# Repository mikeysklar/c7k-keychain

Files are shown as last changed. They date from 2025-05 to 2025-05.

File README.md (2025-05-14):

# c7k-keychain
super thin I2C keyboard

Chording 7 Key - I2C breakout

Ultra-Thin wearable one handed keyboard which can be used with a phone, tablet, computer even from a pocket. It is a full size keybaord in seven buttons.

I2C interface means easy connectivity to modern micrcontrollers and single board computers. This allows maximum flexibility for direct to controller, HID USB or HID BLE interfacing.

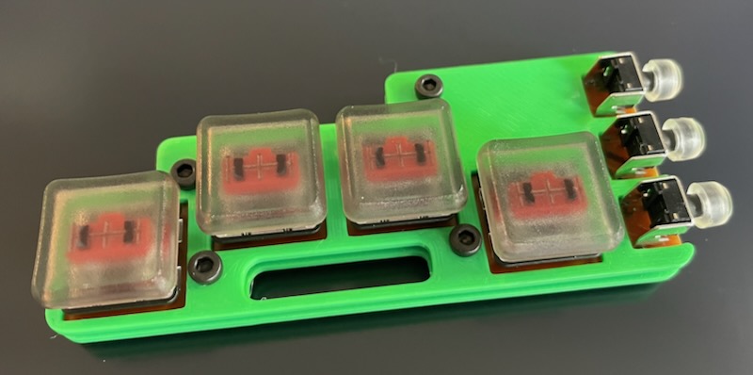
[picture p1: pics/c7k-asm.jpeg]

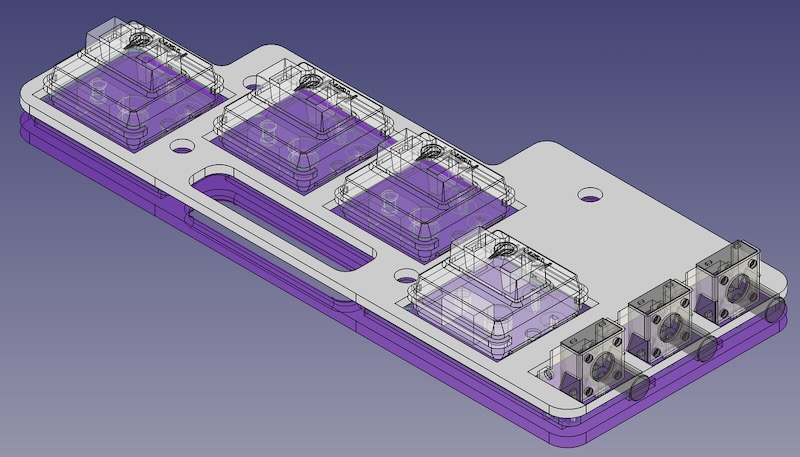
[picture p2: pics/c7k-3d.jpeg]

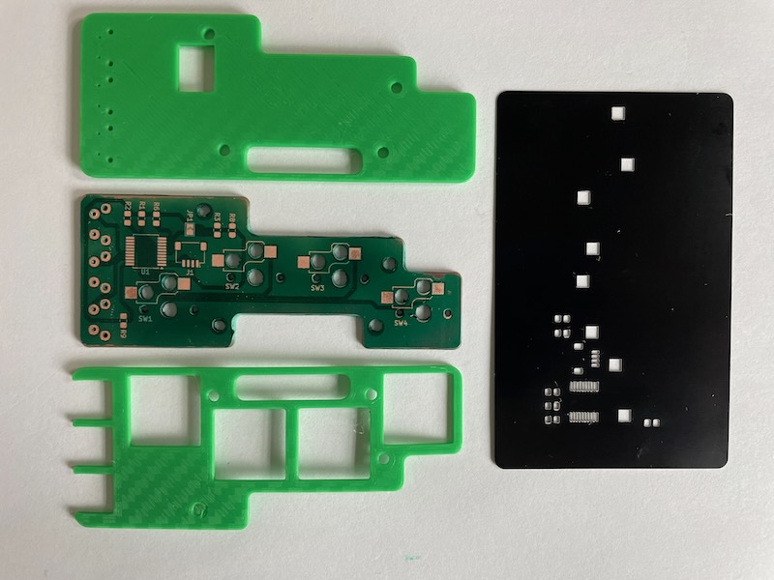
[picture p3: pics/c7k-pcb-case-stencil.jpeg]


center thumb or no modifier :: alpha
```
| Key | Pinky | Ring | Middle | Index | Thumb |
|-----|-------|------|--------|-------|-------|
| a   | x     |      |        |       |       |
| b   | x     |      |        |       | oxo   |
| c   | x     |      |        | x     |       |
| d   |       | x    | x      | x     |       |
| e   |       |      | x      |       |       |
| f   |       | x    | x      |       | oxo   |
| g   |       |      | x      |       | oxo   |
| h   |       | x    |        |       | oxo   |
| i   |       |      | x      |       |       |
| j   |       | x    | x      | x     | oxo   |
| k   | x     |      | x      |       | oxo   |
| l   | x     |      | x      |       |       |
| m   |       |      |        | x     | oxo   |
| n   |       | x    | x      |       |       |
| o   |       | x    |        | x     |       |
| p   | x     | x    | x      |       |       |
| q   | x     | x    | x      | x     | oxo   |
| r   |       |      | x      | x     |       |
| s   | x     |      |        |       |       |
| t   | x     | x    |        |       |       |
| u   | x     | x    | x      | x     |       |
| v   | x     | x    |        |       | oxo   |
| w   |       | x    |        | x     | oxo   |
| x   | x     |      |        | x     | oxo   |
| y   |       |      | x      | x     | oxo   |
| z   | x     | x    | x      |       | oxo   |
| BCK | x     |      | x      | x     |       |
| SPC | x     | x    |        | x     |       |
| DEL | x     |      | x      | x     | oxo   |
```

outside thumb modifier :: numeric

```
| Key   | Pinky | Ring | Middle | Index | Thumb |
|-------|-------|------|--------|-------|-------|
| ONE   |       |      |        | x     | oox   |
| TWO   |       |      | x      |       | oox   |
| THREE |       | x    |        |       | oox   |
| FOUR  | x     |      |        |       | oox   |
| FIVE  |       |      | x      | x     | oox   |
| SIX   |       | x    | x      |       | oox   |
| SEVEN | x     | x    |        |       | oox   |
| EIGHT |       | x    |        | x     | oox   |
| NINE  | x     |      | x      |       | oox   |
| ZERO  |       | x    | x      | x     | oox   |
| ->    | x     |      | x      | x     | oox   |
| <-    | x     | x    |        | x     | oox   |
| ^^    | x     |      |        | x     | oox   |
| vv    | x     | x    | x      | x     | oox   |
| ESC   | x     | x    | x      |       | oox   |
```

inside thumb :: white 

```
| Key            | Pinky | Ring | Middle | Index | Thumb |
|----------------|-------|------|--------|-------|-------|
| space          |       |      |        | x     | xoo   |
| tab            |       |      | x      |       | xoo   |
| period         |       | x    |        |       | xoo   |
| minus          | x     |      |        |       | xoo   |
| comma          |       | x    |        | x     | xoo   |
| enter          |       |      | x      | x     | xoo   |
| backspace      |       | x    | x      |       | xoo   |
| backslash      | x     | x    |        | x     | xoo   |
| forward_slash  | x     | x    |        |       | xoo   |
| grave_accent   | x     | x    | x      | x     | xoo   |
| minus          | x     |      |        |       | xoo   |
| equals         |       | x    |        | x     | xoo   |
| left_bracket   | x     |      | x      |       | xoo   |
| right_bracket  | x     |      |        | x     | xoo   |
| semicolon      | x     | x    |        | x     | xoo   |
| quote          | x     |      | x      | x     | xoo   |
```

inside and center thumb :: modifier layer

```
| Action          | Pinky | Ring | Middle | Index | Thumb |
|-----------------|:-----:|:----:|:------:|:-----:|:-----:|
| Toggle Mouse    |       |      |        |       | oxx   |
| Move Up         |   X   |      |        |       |       |
| Move Right      |       |   X  |        |       |       |
| Move Left       |       |      |   X    |       |       |
| Move Down       |       |      |        |   X   |       |
| Left Click      |   X   |   X  |        |       |       |
| Right Click     |       |      |   X    |   X   |       |
| Middle Click    |       |   X  |   X    |       |       |
| Back (X1)       |   X   |      |        |       |   X   |
| Forward (X2)    |       |      |        |   X   |   X   |
```

inside and outer thumb :: mouse layer

```
| Action       | Pinky | Ring | Middle | Index | Thumb |
|--------------|-------|------|--------|-------|-------|
| Toggle Mouse |       |      |        |       | oxx   |
| Move Up      | x     |      |        |       |       |
| Move Right   |       | x    |        |       |       |
| Move Left    |       |      | x      |       |       |
| Move Down    |       |      |        | x     |       |
```

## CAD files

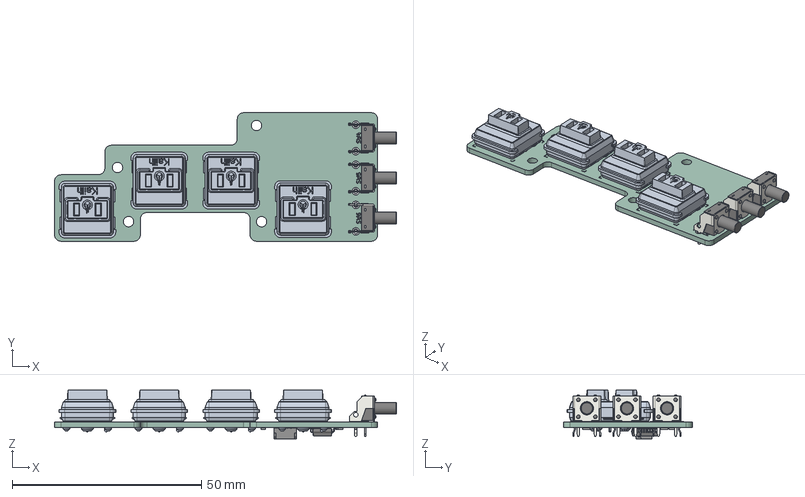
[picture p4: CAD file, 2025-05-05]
c7k-left-hand/c7k-left-hand.step
90.4 x 34.0 x 12.9 mm
SW_Tactile_SPST_Angled_PTS645Vx83-2LFS x 3
Kailh LP Choc Burnt Orange x 4
R_0805_2012Metric x 6
SSOP-20_5.3x7.2mm_P0.65mm
SPARKFUN_QWIIC_RIGHT_ANGLE
c7k-left-hand_pad
c7k-left-hand_silkscreen
c7k-left-hand_PCB

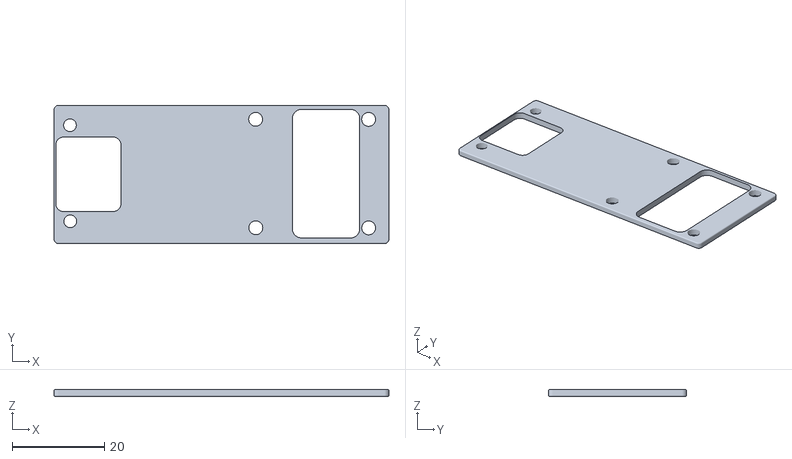
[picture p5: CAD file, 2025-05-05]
case/c7k-keychain-nnv2-cover.stl
72.6 x 30.0 x 1.50

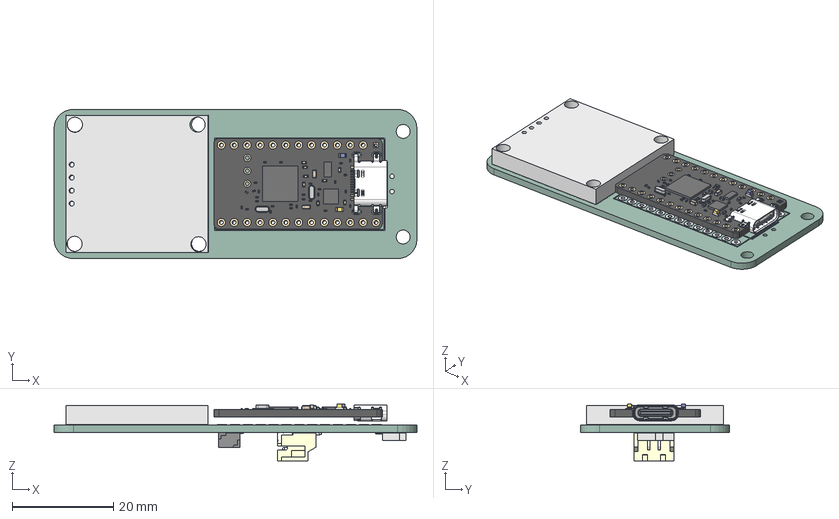
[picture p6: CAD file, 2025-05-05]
nnv2-oled-toupee/nicenano-breakout.step
71.5 x 29.4 x 11.2 mm
nice!nano v1.0
mcu-chip-ic-2set-leg v1
LED_0603_1608Metric_ON v1
LED_0603_1608Metric_ON v1(Mirror)
Crystal Oscillator v3
Crystal Oscillator v3 (1)
usb4520-03-0-a v1
C0201 v1 x 28
C0402 v1 x 8
0603 v1 x 2
SPARKFUN_QWIIC_RIGHT_ANGLE
S2B-PH-SM4-TB
nnv2-oled-toupee_pad
nnv2-oled-toupee_silkscreen
nnv2-oled-toupee_PCB

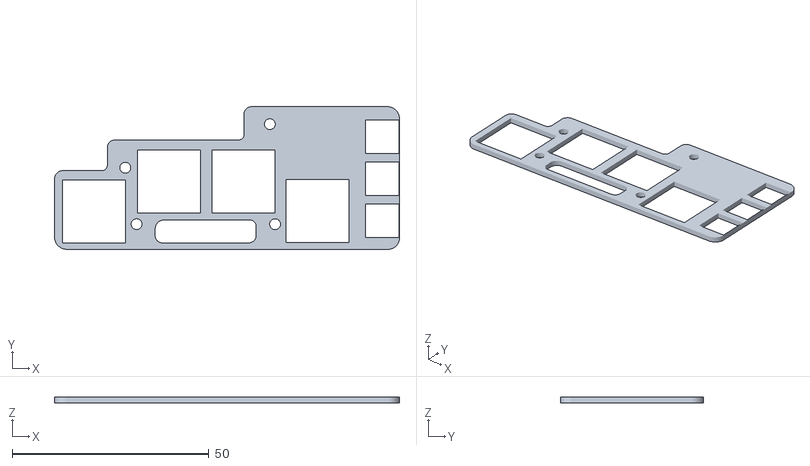
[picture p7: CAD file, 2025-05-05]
case/c7k-keychain-c7k-cover.stl
87.6 x 36.2 x 1.50

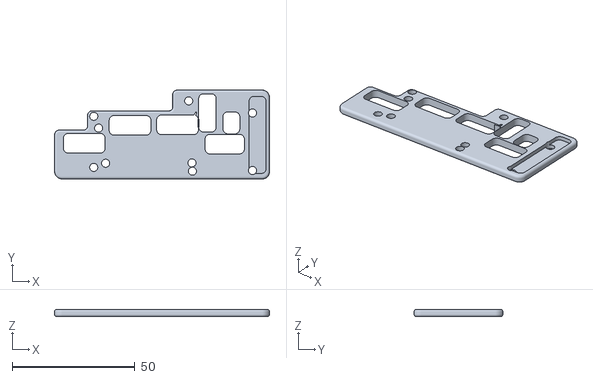
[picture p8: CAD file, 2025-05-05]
case/c7k-keychain-center-plate.stl
87.6 x 36.2 x 3.00

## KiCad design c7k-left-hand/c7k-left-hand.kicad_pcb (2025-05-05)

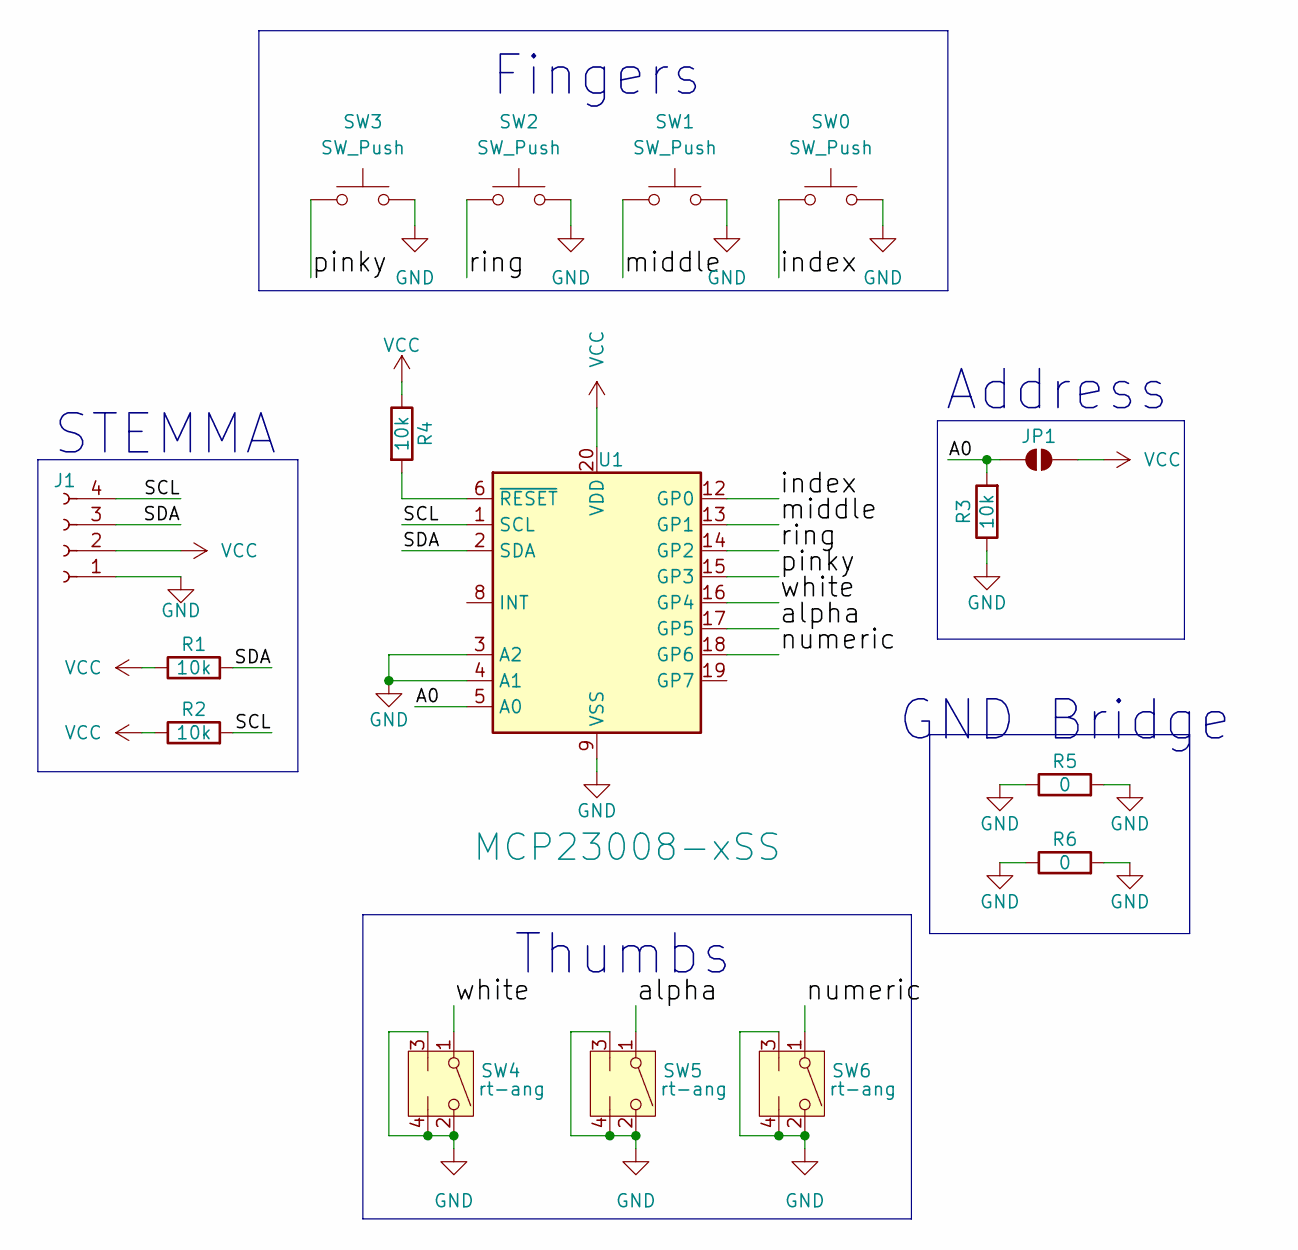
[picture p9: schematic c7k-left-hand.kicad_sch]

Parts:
J1: Conn_01x04_Socket; JST_SH_SM04B-SRSS-TB_1x04-1MP_P1.00mm_Horizontal
JP1: SolderJumper_2_Open; SolderJumper-2_P1.3mm_Open_TrianglePad1.0x1.5mm
R1, R2, R3, R4: 10k; R_0805_2012Metric_Pad1.20x1.40mm_HandSolder
R5, R6: 0; R_0805_2012Metric_Pad1.20x1.40mm_HandSolder
SW0, SW1, SW2, SW3: SW_Push; Kailh_socket_PG1350
SW4, SW5, SW6: rt-ang; SW_Tactile_SPST_Angled_PTS645Vx83-2LFS
U1: MCP23008-xSS; SSOP-20_5.3x7.2mm_P0.65mm

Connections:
/A0: JP1.1 (A), R3.2, U1.5 (A0)
/SCL: J1.4, R2.2, U1.1 (SCL)
/SDA: J1.3, R1.2, U1.2 (SDA)
/alpha: SW5.1, U1.17 (GP5)
/index: SW0.1, U1.12 (GP0)
/middle: SW1.1, U1.13 (GP1)
/numeric: SW6.1, U1.18 (GP6)
/pinky: SW3.1, U1.15 (GP3)
/ring: SW2.1, U1.14 (GP2)
/white: SW4.1, U1.16 (GP4)
GND: J1.1, R3.1, R5.1, R5.2, R6.1, R6.2, SW0.2, SW1.2, SW2.2, SW3.2, SW4.2, SW4.3 (L), SW4.4 (L), SW5.2, SW5.3 (L), SW5.4 (L), SW6.2, SW6.3 (L), SW6.4 (L), U1.3 (A2), U1.4 (A1), U1.9 (VSS)
unnamed: R4.2, U1.6 (~RESET)
VCC: J1.2, JP1.2 (B), R1.1, R2.1, R4.1, U1.20 (VDD)

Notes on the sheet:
GND Bridge
Fingers
Thumbs
Address
STEMMA

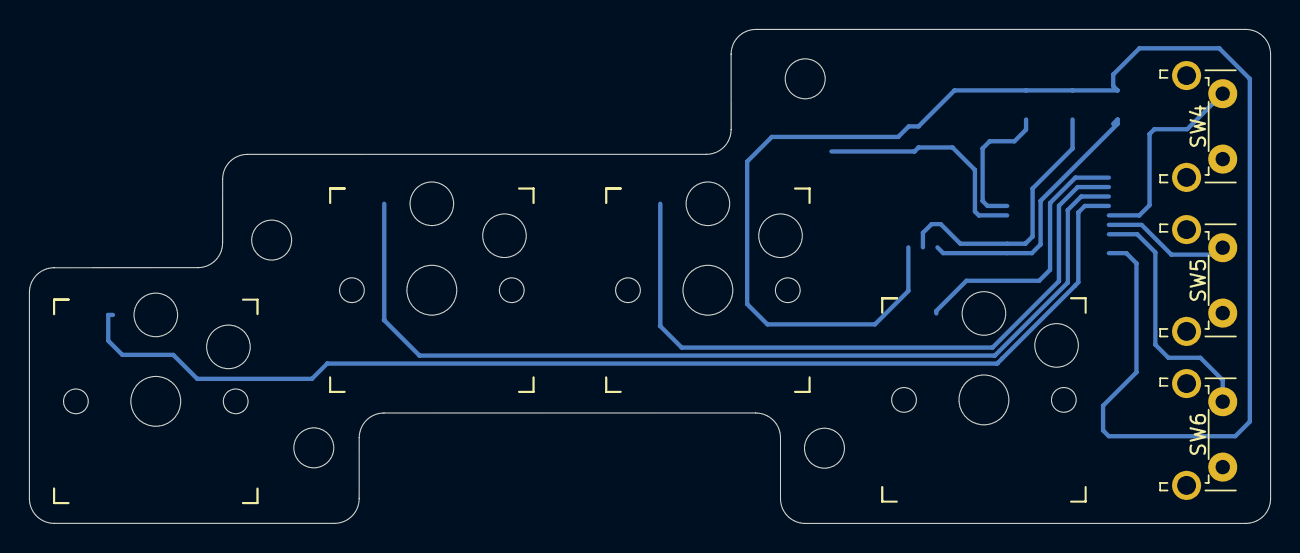
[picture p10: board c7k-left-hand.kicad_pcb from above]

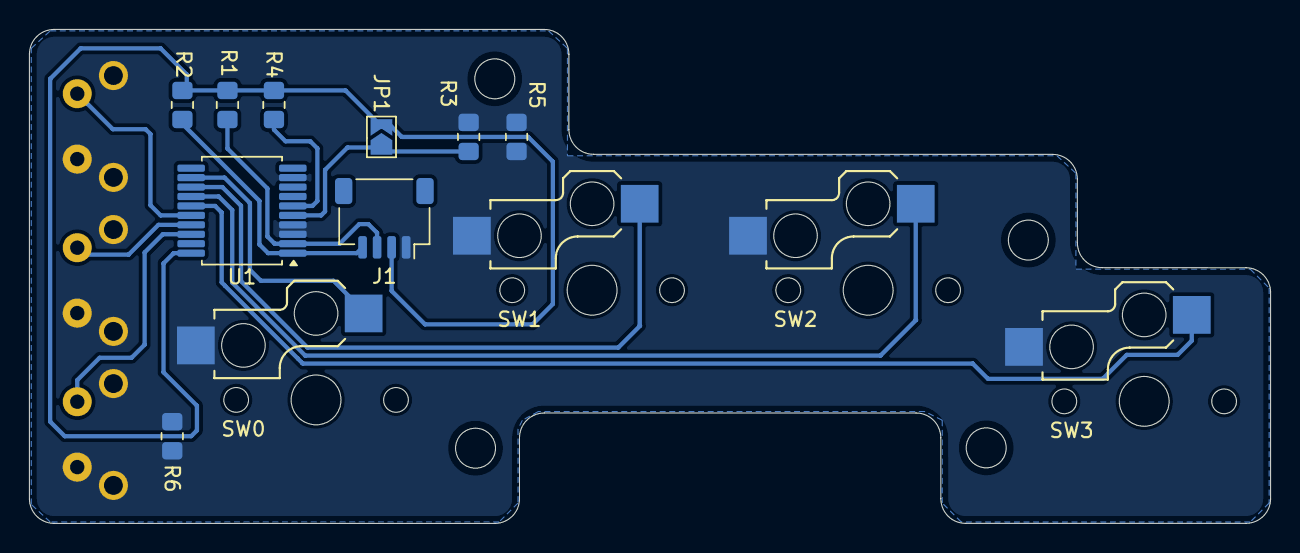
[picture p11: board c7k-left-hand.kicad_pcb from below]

Board: 2 copper layers, 85.4 x 34.0 mm, 16 parts (9 on the bottom side), 13 nets.

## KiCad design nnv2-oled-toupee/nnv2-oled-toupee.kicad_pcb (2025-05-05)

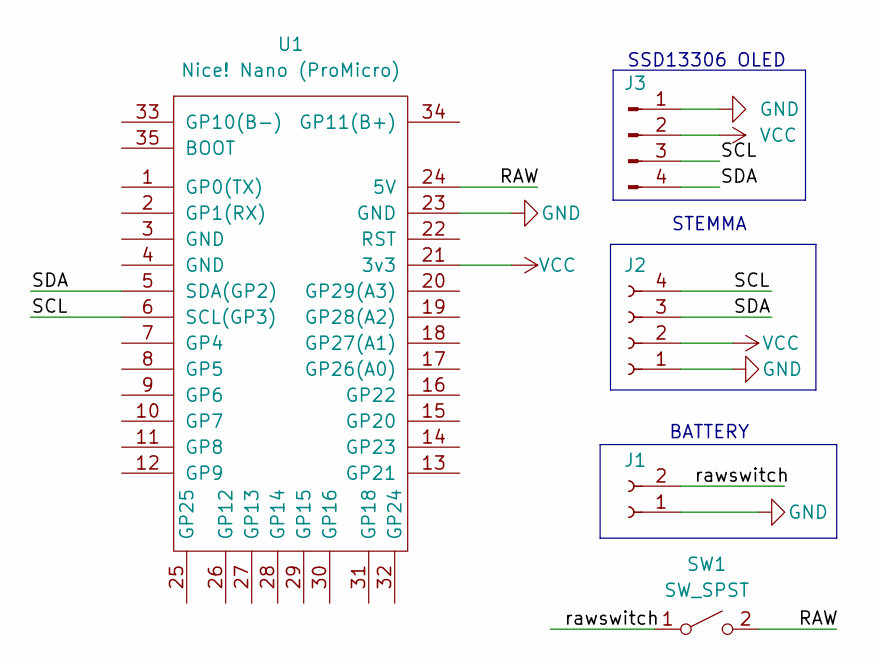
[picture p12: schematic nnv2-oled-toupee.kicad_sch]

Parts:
J1: Conn_01x02_Socket; JST_PH_S2B-PH-SM4-TB_1x02-1MP_P2.00mm_Horizontal
J2: Conn_01x04_Socket; JST_SH4
J3: Conn_01x04_Pin; ssd1306-toupee
SW1: SW_SPST; Untitled
U1: Nice! Nano (ProMicro); SuperMini NRF52840

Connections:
/RAW: SW1.2 (B), U1.24 (5V)
/SCL: J2.4, J3.3, U1.6 (SCL(GP3))
/SDA: J2.3, J3.4, U1.5 (SDA(GP2))
/rawswitch: J1.2, SW1.1 (A)
GND: J1.1, J2.1, J3.1, U1.23 (GND)
VCC: J2.2, J3.2, U1.21 (3v3)

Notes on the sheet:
STEMMA
BATTERY
SSD13306 OLED

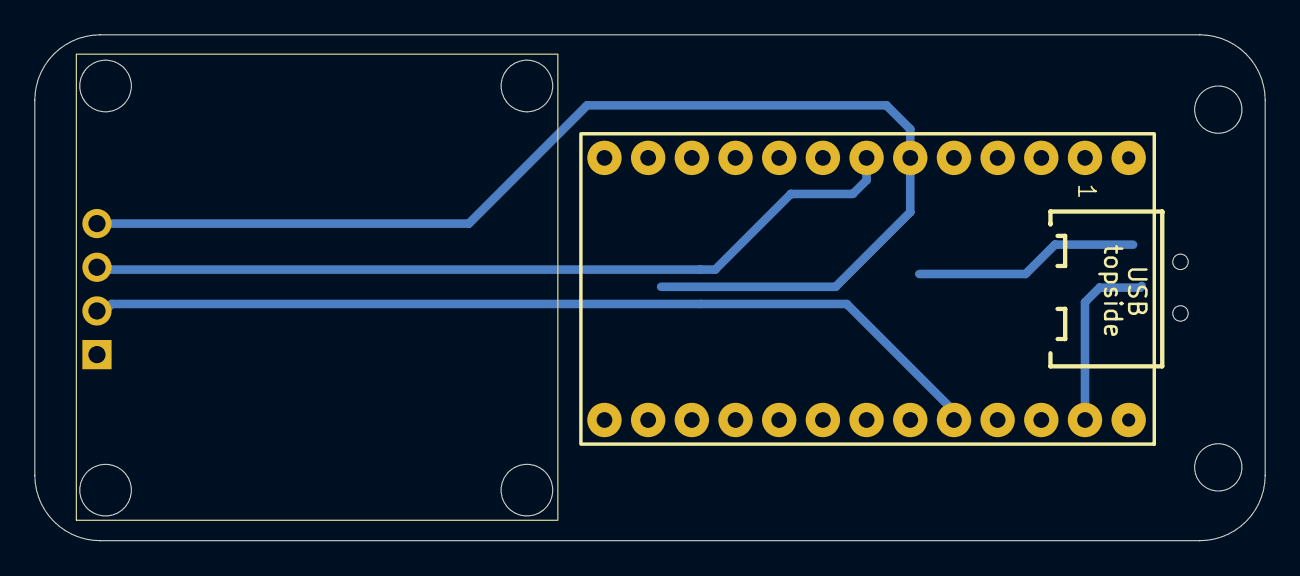
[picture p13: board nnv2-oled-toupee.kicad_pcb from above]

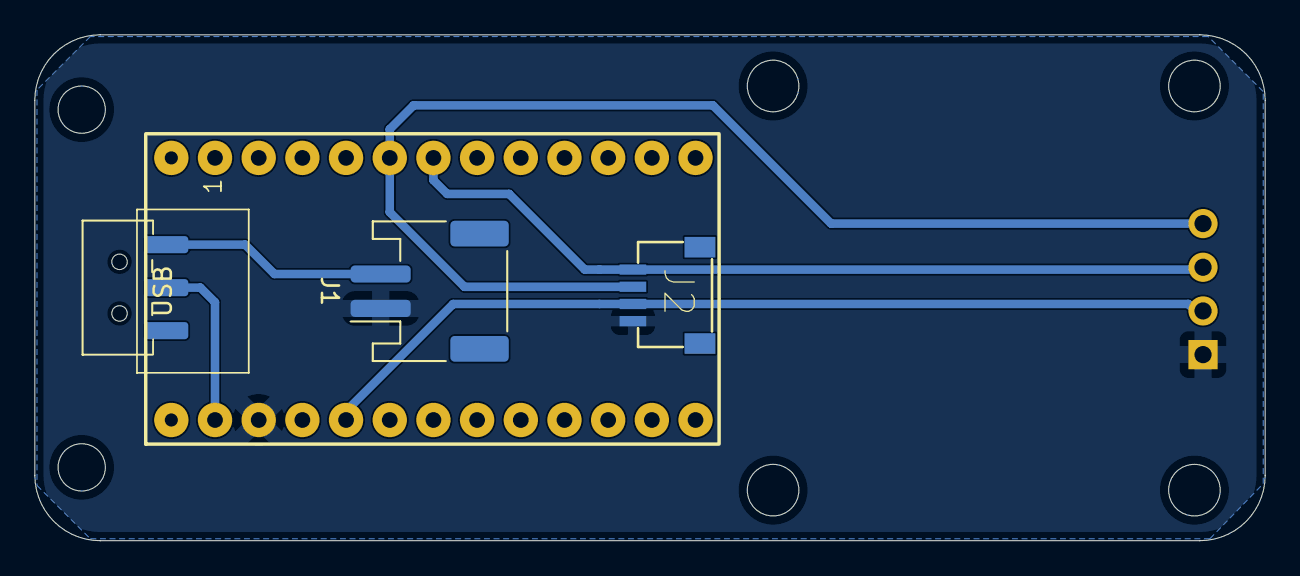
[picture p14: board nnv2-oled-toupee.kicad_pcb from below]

Board: 2 copper layers, 71.5 x 29.4 mm, 5 parts (3 on the bottom side), 6 nets.

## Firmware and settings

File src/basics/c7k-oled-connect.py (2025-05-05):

import board
import busio
import digitalio
import displayio
import microcontroller
import time
from i2cdisplaybus import I2CDisplayBus
import adafruit_displayio_ssd1306
from adafruit_display_text import label
import terminalio
import adafruit_ble
from adafruit_ble.advertising.standard import ProvideServicesAdvertisement
from adafruit_ble.services.standard.hid import HIDService
from adafruit_hid.keyboard import Keyboard
from adafruit_hid.keycode import Keycode
from adafruit_hid.mouse import Mouse
from adafruit_mcp230xx.mcp23008 import MCP23008

# ——— OLED Power & Reset Setup ———
vcc = digitalio.DigitalInOut(board.VCC_OFF)
vcc.direction = digitalio.Direction.OUTPUT
vcc.value = True
# allow 3.3 V rail to settle
time.sleep(0.2)

# release any previous display bindings and free RESET/DC pins
displayio.release_displays()
for p in (microcontroller.pin.P0_20, microcontroller.pin.P0_17):
    try:
        digitalio.DigitalInOut(p).deinit()
    except Exception:
        pass

# ——— I²C Bus (400 kHz) ———
i2c = busio.I2C(board.SCL, board.SDA, frequency=400000)

# ——— SSD1306 OLED Initialization ———
OLED_ADDR = 0x3C  # confirmed working
bus = I2CDisplayBus(i2c, device_address=OLED_ADDR)
display = adafruit_displayio_ssd1306.SSD1306(bus, width=128, height=64)
splash = displayio.Group()
display.root_group = splash
status_lbl = label.Label(terminalio.FONT, text="Ready", x=0, y=16)
splash.append(status_lbl)

def update_display(msg: str):
    status_lbl.text = msg

# ——— MCP23008 Expander Setup ———
mcp = MCP23008(i2c)
for i in range(7):
    pin = mcp.get_pin(i)
    pin.direction = digitalio.Direction.INPUT
    pin.pull = digitalio.Pull.UP

# ——— BLE HID Setup ———
ble = adafruit_ble.BLERadio()
hid = HIDService()
advertisement = ProvideServicesAdvertisement(hid)
keyboard = Keyboard(hid.devices)
mouse = Mouse(hid.devices)

# ——— Chording Configuration ———
pin_to_key_index = {i: i for i in range(7)}
pressed_keys = [False] * 7
pending_combo = None
last_combo_time = 0
last_hold_time = 0
last_release_time = 0

# Timing parameters
MIN_HOLD   = 0.01
COMBO_WIN  = 0.01
COOLDOWN   = 0.01
RELEASE_WIN= 0.01

# Modifier layer
modifier_layer_armed = False
held_modifier = None
layer_trigger_chord = (5, 6)
modifier_chords = {
    (0,): Keycode.LEFT_SHIFT,
    (1,): Keycode.LEFT_CONTROL,
    (2,): Keycode.LEFT_ALT,
    (3,): Keycode.LEFT_GUI
}

# Mouse layer\mouse_layer_armed = False
mouse_trigger_chord = (4, 5)

# Chord → Key mapping
chords = {
    (0,): Keycode.E,   (1,): Keycode.I,    (2,): Keycode.A,
    (3,): Keycode.S,   (4,): Keycode.SPACE,(0,1): Keycode.R,
    (0,2): Keycode.O,  (0,3): Keycode.C,    (1,2): Keycode.N,
    (1,3): Keycode.L,  (2,3): Keycode.T,    (0,5): Keycode.M,
    (1,5): Keycode.G,  (2,5): Keycode.H,    (3,5): Keycode.B,
    (0,4): Keycode.SPACE,
    (0,1,5): Keycode.Y,(0,2,5): Keycode.W,  (0,3,5): Keycode.X,
    (1,2,5): Keycode.F,(1,3,5): Keycode.K,  (2,3,5): Keycode.V,
    (0,1,2): Keycode.D,(1,2,3): Keycode.P,
    (0,1,2,5):Keycode.J,(1,2,3,5):Keycode.Z,
    (0,1,2,3):Keycode.U,(0,1,2,3,5):Keycode.Q,
    (0,6): Keycode.ONE,(1,6): Keycode.TWO,  (2,6): Keycode.THREE,
    (3,6):Keycode.FOUR,(0,1,6):Keycode.FIVE,(1,2,6):Keycode.SIX,
    (2,3,6):Keycode.SEVEN,(0,2,6):Keycode.EIGHT,(1,3,6):Keycode.NINE,
    (0,3,6):Keycode.UP_ARROW,
    (0,1,2,6):Keycode.ZERO,
    (0,1,3,6):Keycode.RIGHT_ARROW,
    (0,2,3,6):Keycode.LEFT_ARROW,
    (1,2,3,6):Keycode.ESCAPE,
    (0,1,2,3,6):Keycode.DOWN_ARROW,
    (6,): Keycode.BACKSPACE,
    (1,4):Keycode.TAB, (2,4):Keycode.PERIOD, (3,4):Keycode.MINUS,
    (0,2,3):Keycode.SPACE,(0,1,3):Keycode.BACKSPACE,
    (2,3,4):Keycode.FORWARD_SLASH,(0,1,4):Keycode.ENTER,
    (0,2,4):Keycode.COMMA,(0,2,4):Keycode.EQUALS,
    (1,3,4):Keycode.LEFT_BRACKET,(0,3,4):Keycode.RIGHT_BRACKET,
    (2,3,4):Keycode.BACKSLASH,(1,2,4):Keycode.BACKSPACE,
    (0,1,3,4):Keycode.QUOTE,(0,2,3,4):Keycode.SEMICOLON,
    (0,1,2,3,4):Keycode.GRAVE_ACCENT
}

# ——— Main Loop ———
while True:
    # Advertise until connected
    update_display("Advertising")
    ble.start_advertising(advertisement)
    while not ble.connected:
        time.sleep(0.05)
    ble.stop_advertising()
    update_display("Connected")

    # Process chords while connected
    while ble.connected:
        for pin, idx in pin_to_key_index.items():
            pressed_keys[idx] = not mcp.get_pin(pin).value
        # chord handling logic...
        time.sleep(0.05)

    # Disconnected: show status and loop back
    update_display("Disconnected")
    time.sleep(0.5)
